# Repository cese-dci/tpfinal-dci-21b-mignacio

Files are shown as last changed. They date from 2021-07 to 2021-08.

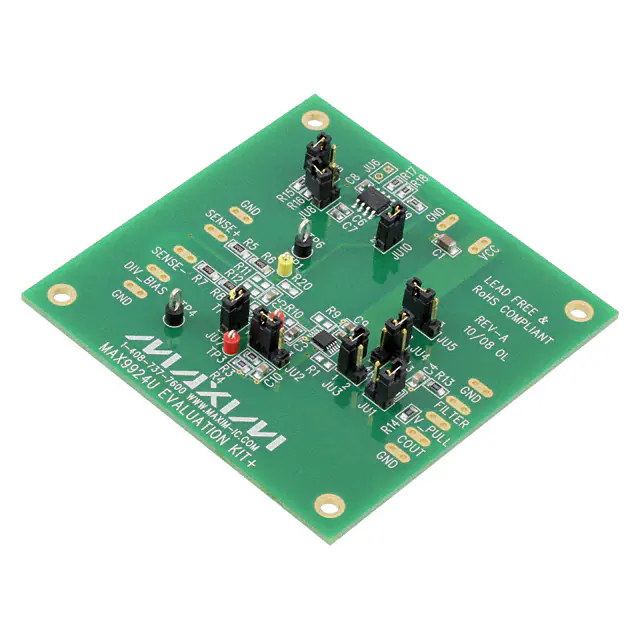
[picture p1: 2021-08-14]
doc/propuesta/MAX9924UEVKIT+.webp

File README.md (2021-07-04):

## Trabajo práctico final de la asignatura DCI ##
Este repositorio contiene el trabajo práctico final para la asignatura de Diseño de Circuitos Impresos de la carrera de posgrado de FIUBA.

* Autor: Ignacio Moya
* Título corto del trabajo:  Poncho MAX9924 para EDU-CIAA 
* Descripción:  Poncho para el circuito integrado MAX9924, que funciona como interface para sensores de reluctancia variable.

## Licencia de este trabajo ##
GPL http://www.gnu.org/licenses/gpl-3.0.html

## Estructura del repositorio ##

* doc: Toda la información sobre el circuito, principalmente de autoría o procesamiento propio. Por ejemplo:
  * Notas de ingeniería propias.
  * Notas de aplicación propias.
  * Estudios previos, estado del arte, resumen de las investigaciones.
  * Notas con cálculos.
  * Dibujos adicionales.
  * Fotos de los prototipos.
  * Presupuestos, cotizaciones.
* info: Toda la iformación recolectada, principalmente de terceros, como por ejemplo:
  * Hojas de datos.
  * Notas de aplicación.
  * Info de productos comerciales.
  * Info en internet.
* pcb: Archivos de diseño esquemático y pcb.

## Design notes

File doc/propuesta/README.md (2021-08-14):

## Propuesta ##
Se propone realizar la adaptación de un kit de evaluación para el integrado MAX9924 a un poncho para EDU-CIAA. Su función es convertir la señal de un sensor de reluctancia variable, o sensor "inductivo", usado comunmente para medir revoluciones y la posición del diferencial en motores de combustión interna.
El circuito también incluye un generador de onda triangular que se puede utilizar para emular la señal de uno de estos sensores. El generador de señal está implementado con un integrado MAX9000 que es una combinación de amplificador operacional más un comparador con referencia de voltaje interna.

* Nombre corto del módulo: Replica kit evaluación 9924
* Enlace al esquemático del módulo: https://datasheets.maximintegrated.com/en/ds/MAX9924UEVKIT.pdf
* URL de la foto del módulo (vista superior): https://media.digikey.com/Photos/Maxim%20Photos/MAX9924UEVKIT+.JPG
* Descripción o detalles del módulo, o URL donde encontrar la misma:
* El modulo es un kit de evaluación para sensores de reluctancia variable se suelen conocer como sensores inductivos. Para mi aplicación específica, lo utilizaré para medir la velocidad y posición del cigüeñal de un motor de combustión interna.
* Modificaciones al módulo: Se modificará el módulo para que sea un poncho para la EDU-CIAA
* Dispone del módulo para inspeccionarlo?: No

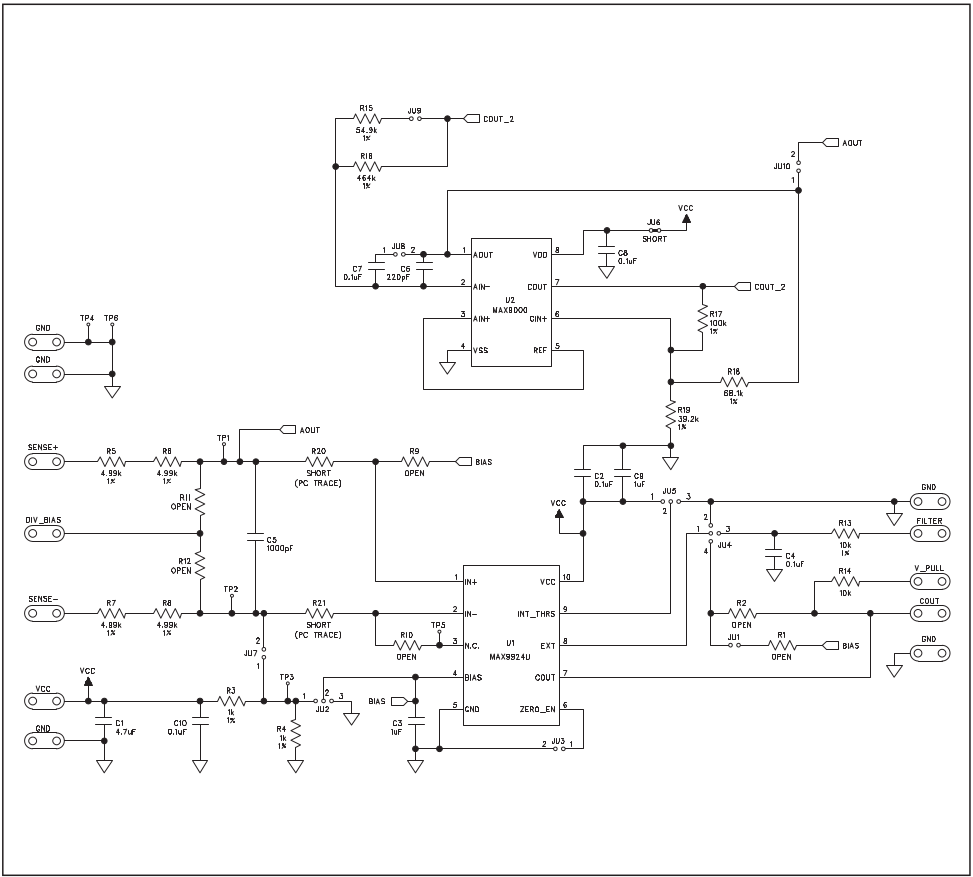
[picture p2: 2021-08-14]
doc/propuesta/esquematico.png

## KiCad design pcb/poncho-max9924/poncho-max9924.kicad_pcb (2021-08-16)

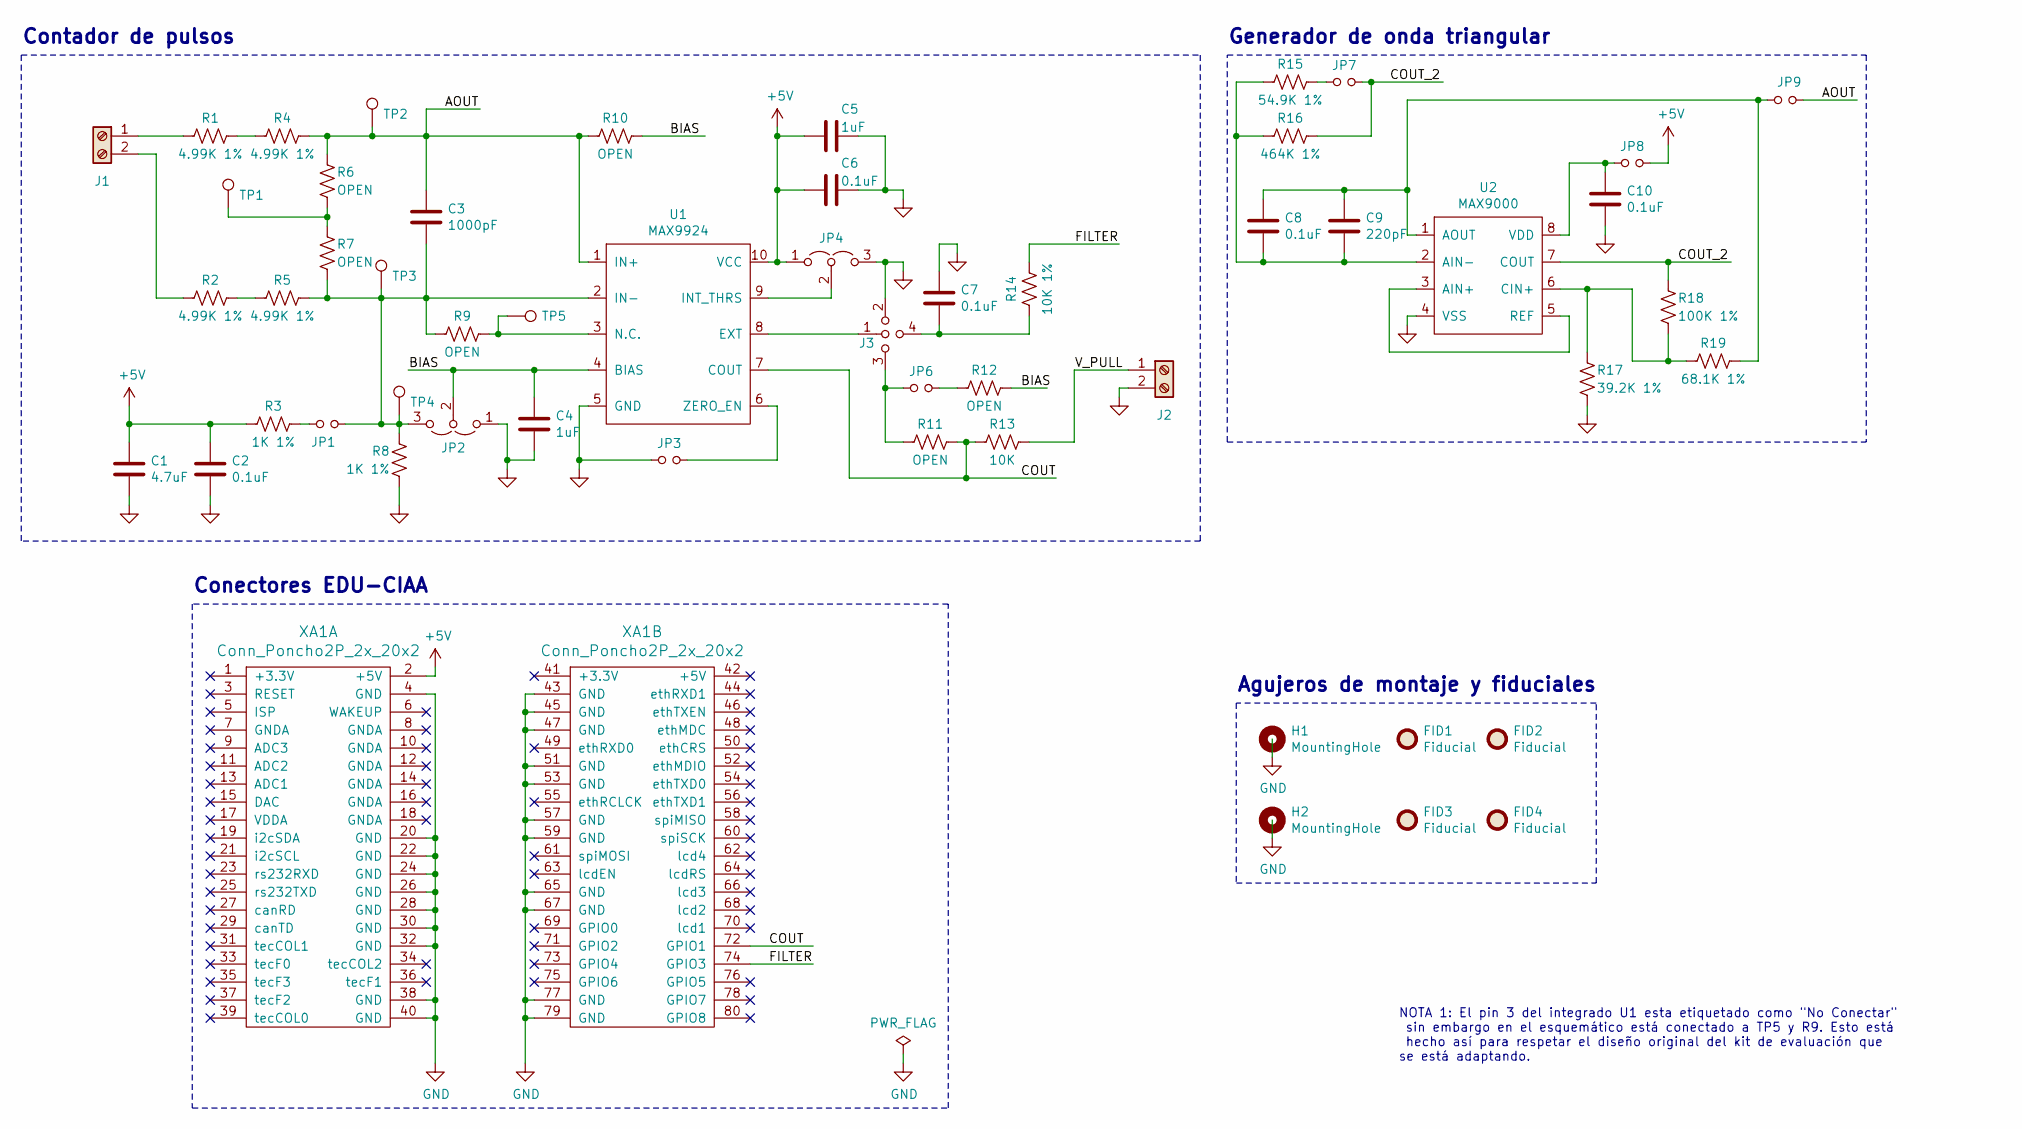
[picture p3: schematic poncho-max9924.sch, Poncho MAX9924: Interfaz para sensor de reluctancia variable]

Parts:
C1: 4.7uF; C_0805_2012Metric_Pad1.18x1.45mm_HandSolder
C2, C6, C7, C8, C10: 0.1uF; C_0805_2012Metric_Pad1.18x1.45mm_HandSolder
C3: 1000pF; C_0805_2012Metric_Pad1.18x1.45mm_HandSolder
C4, C5: 1uF; C_0805_2012Metric_Pad1.18x1.45mm_HandSolder
C9: 220pF; C_0805_2012Metric_Pad1.18x1.45mm_HandSolder
FID1, FID2, FID3, FID4: Fiducial; Fiducial_0.5mm_Mask1mm
H1, H2: MountingHole; MountingHole_3.5mm_Pad
J1, J2: Screw_Terminal_01x02; TerminalBlock_bornier-2_P5.08mm
J3: jumper_4_open; PinHeader_1x03_1x01_P2.54mm_Vertical
JP1, JP3, JP6, JP7, JP8, JP9: Jumper_NO_Small; PinHeader_1x02_P2.54mm_Vertical
JP2, JP4: Jumper_3_Open; PinHeader_1x03_P2.54mm_Vertical
R1, R2, R4, R5: 4.99K 1%; R_0805_2012Metric_Pad1.20x1.40mm_HandSolder
R3, R8: 1K 1%; R_0805_2012Metric_Pad1.20x1.40mm_HandSolder
R6, R7, R9, R10, R11, R12: OPEN; R_0805_2012Metric_Pad1.20x1.40mm_HandSolder
R13: 10K; R_0805_2012Metric_Pad1.20x1.40mm_HandSolder
R14: 10K 1%; R_0805_2012Metric_Pad1.20x1.40mm_HandSolder
R15: 54.9K 1%; R_0805_2012Metric_Pad1.20x1.40mm_HandSolder
R16: 464K 1%; R_0805_2012Metric_Pad1.20x1.40mm_HandSolder
R17: 39.2K 1%; R_0805_2012Metric_Pad1.20x1.40mm_HandSolder
R18: 100K 1%; R_0805_2012Metric_Pad1.20x1.40mm_HandSolder
R19: 68.1K 1%; R_0805_2012Metric_Pad1.20x1.40mm_HandSolder
TP1, TP2, TP3, TP4, TP5: TestPoint; TestPoint_Pad_D2.0mm
U1: MAX9924; SOP50P490X110-10N; Digikey PN MAX9924UAUB+T
U2: MAX9000; SOP65P490X110-8N; Digikey PN MAX9000ESA+
XA1: Conn_Poncho2P_2x_20x2; Conn_Poncho_SinBorde

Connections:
+5V: C1.1, C2.1, C5.2, C6.2, JP4.1 (A), JP8.2, R3.2, U1.10 (VCC), XA1.2 (+5V)
/AOUT: C3.1, JP9.2, R4.1, R6.1, R10.2, TP2.1, U1.1 (IN+)
/BIAS: C4.1, JP2.2 (C), R10.1, R12.1, U1.4 (BIAS)
/COUT: R11.1, R13.2, U1.7 (COUT), XA1.72 (GPIO1)
/COUT_2: JP7.1, R16.1, R18.1, U2.7 (COUT)
/FILTER: R14.1, XA1.74 (GPIO3)
/V_PULL: J2.1, R13.1
GND: C1.2, C2.2, C4.2, C5.1, C6.1, C7.1, C10.1, J2.2, J3.2, JP2.1 (A), JP3.2, JP4.3 (B), R8.1, R17.2, U1.5 (GND), U2.4 (VSS), XA1.4 (GND), XA1.20 (GND), XA1.22 (GND), XA1.24 (GND), XA1.26 (GND), XA1.28 (GND), XA1.30 (GND), XA1.32 (GND), XA1.38 (GND), XA1.40 (GND), XA1.43 (GND), XA1.45 (GND), XA1.47 (GND), XA1.51 (GND), XA1.53 (GND), XA1.57 (GND), XA1.59 (GND), XA1.65 (GND), XA1.67 (GND), XA1.77 (GND), XA1.79 (GND)
unnamed: C3.2, JP1.1, JP2.3 (B), R5.1, R7.2, R8.2, R9.2, TP3.1, TP4.1, U1.2 (IN-)
unnamed: C7.2, J3.4, R14.2
unnamed: C8.1, C9.1, R15.2, R16.2, U2.2 (AIN-)
unnamed: C8.2, C9.2, JP9.1, R19.1, U2.1 (AOUT)
unnamed: C10.2, JP8.1, U2.8 (VDD)
unnamed: J1.1, R1.2
unnamed: J1.2, R2.2
unnamed: J3.1, U1.8 (EXT)
unnamed: J3.3, JP6.2, R11.2
unnamed: JP1.2, R3.1
unnamed: JP3.1, U1.6 (ZERO_EN)
unnamed: JP4.2 (C), U1.9 (INT_THRS)
unnamed: JP6.1, R12.2
unnamed: JP7.2, R15.1
unnamed: R1.1, R4.2
unnamed: R2.1, R5.2
unnamed: R6.2, R7.1, TP1.1
unnamed: R9.1, TP5.1, U1.3 (N.C.)
unnamed: R17.1, R18.2, R19.2, U2.6 (CIN+)
unnamed: U2.3 (AIN+), U2.5 (REF)

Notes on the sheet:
Generador de onda triangular
Contador de pulsos
Conectores EDU-CIAA
NOTA 1: El pin 3 del integrado U1 esta etiquetado como "No Conectar" sin embargo en el esquemático está conectado a TP5 y R9. Esto está hecho así para respetar el diseño original del kit de evaluación que se está adaptando.
Agujeros de montaje y fiduciales

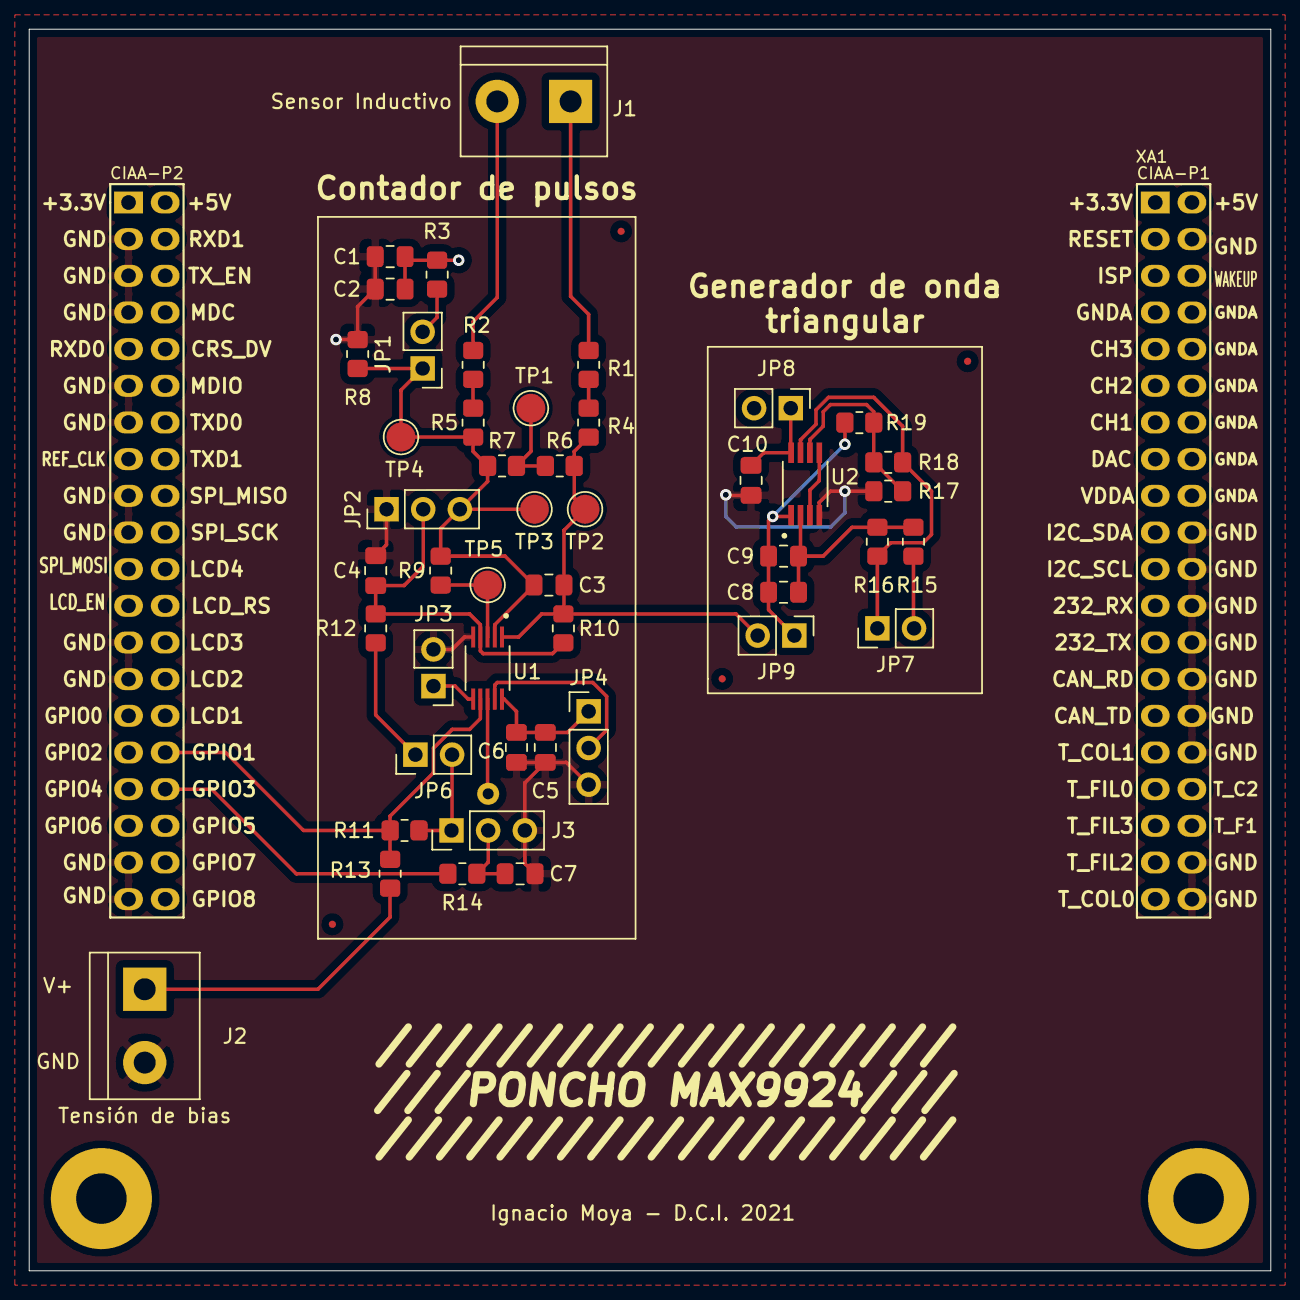
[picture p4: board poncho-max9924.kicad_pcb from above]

Board: 2 copper layers, 86.0 x 86.0 mm, 54 parts (0 on the bottom side), 28 nets.

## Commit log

2021-07-04 Se completaron datos de autor y licencia en README.md raíz y se agregaron hojas de datos del circuito integrado y del módulo de evaluación
2021-07-04 Se agregó información de la propuesta
2021-07-04 Se crea proyecto de kikad y se agrega bibliotecas de poncho ciaa
    [poncho-max9924.kicad_pcb, poncho-max9924.sch]
2021-07-11 esquematico copiado 100%, falta adaptar a poncho
    [poncho-max9924.sch]
2021-07-17 avances en el esquematico
    [poncho-max9924.sch]
2021-07-20 Esquematico listo para primer revision
    [poncho-max9924.sch]
2021-07-21 Se realizaron correcciones en base a comentarios del revisor M. Castello
    [poncho-max9924.sch]
2021-07-22 Correccion de error ERC en terminal de masa
    [poncho-max9924.sch]
2021-07-24 Se crearon huellas faltantes. Se asignaron huellas a todos los componentes y se hizo una primera ubicacion de componentes en el circuito impreso
    [poncho-max9924.sch]
2021-07-27 Se agregaron modelos 3D de todos los componentes y sus footprints. Se re trabajo el posicionamiento de componentes en la placa.
    [poncho-max9924.kicad_pcb, poncho-max9924.sch]
2021-08-10 primer routeado
    [poncho-max9924.kicad_pcb, poncho-max9924.sch]
2021-08-14 correcciones y ruteo listo, falta hacer U2 multiparte
    [poncho-max9924.kicad_pcb, poncho-max9924.sch]
2021-08-16 Se corrigieron errores en DRC y se agregó más info de fabricación en PCB
    [poncho-max9924.kicad_pcb]

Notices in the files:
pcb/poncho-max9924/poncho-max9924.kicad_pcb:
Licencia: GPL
